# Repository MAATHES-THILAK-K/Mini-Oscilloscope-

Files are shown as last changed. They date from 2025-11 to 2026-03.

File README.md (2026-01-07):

# **Mini Oscilloscope – Arduino + SH1106 OLED**

A compact oscilloscope built using Arduino, an SH1106 OLED module, and a simple analog front-end.
Includes auto-range, trigger detection, waveform plotting, and frequency/duty-cycle measurement.

> **Reference Project Used:**
> This build was inspired by the project on Instructables:
> *“Build Your Own Arduino Nano Based DIY Oscilloscope”*
> *https://www.instructables.com/Build-Your-Own-Arduino-Nano-Based-DIY-Oscilloscope/*

---

## 🔧 **Features**

* SH1106 128×64 OLED display
* Auto/Manual voltage ranges
* Time-base options from **200 ms/div** to **200 µs/div**
* Trigger detection (rising & falling edge)
* Frequency and duty-cycle calculation
* Average voltage measurement
* EEPROM settings storage
* Battery measurement mode

---

## 📦 **Hardware**

### **Core Components**

* Arduino Nano (ATmega328P)
* SH1106 128×64 I²C OLED display
* Tactile push buttons (4×: SELECT, UP, DOWN, HOLD)
* Voltage divider resistors
* Schottky diode
* 104 capacitor
* Breadboard or custom PCB
* Jumper wires
* 5V regulated power supply

### **Additional Interface Components**

* Input attenuator (1× / 10×)
* User control buttons.

---

## 🧪 **How It Works**

* Samples analog input using ADC with a variable prescaler
* Computes minimum, maximum, and average voltage
* Detects trigger events to stabilize waveform display
* Calculates frequency and duty cycle using edge-cross detection
* Renders waveform using the **Adafruit GFX** library

---

## 🖼 **Photos / Screenshots**

Add images inside the `Images/` folder once your hardware build is ready.

---

## 📁 **Code Structure**

```
MiniOscilloscope/
├── src/
│   └── miniOscilloscope.ino
├── README.md
├── LICENSE
└── Images/
```

---

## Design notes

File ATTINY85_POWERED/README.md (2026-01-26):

# ATtiny85 Powered Mini Oscilloscope – PCB Design

This repository contains the complete PCB design files for a **compact, low-cost mini oscilloscope** powered by the **ATtiny85 microcontroller**.  
The project is intended for **educational, experimental, and embedded systems learning purposes**.

---

## 📷 PCB Preview

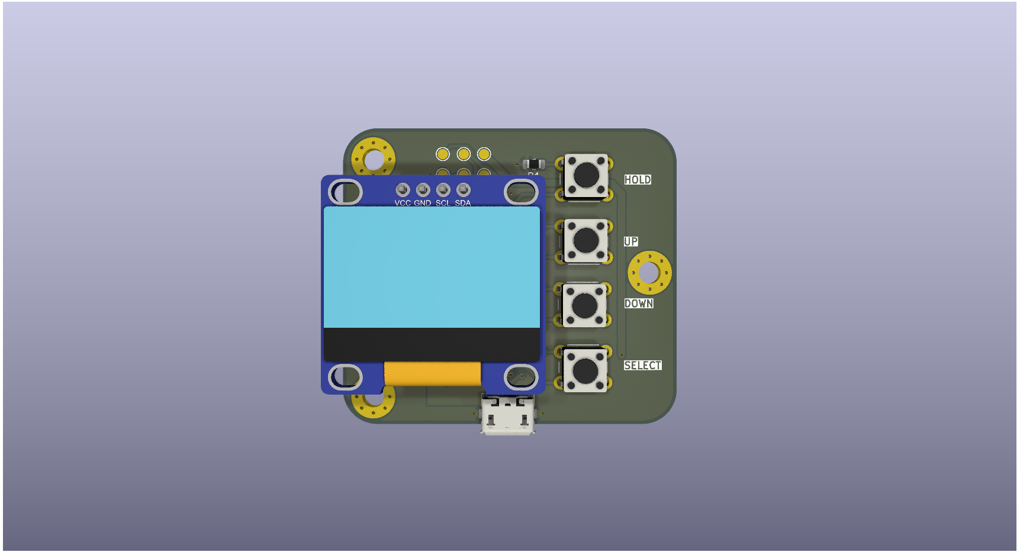
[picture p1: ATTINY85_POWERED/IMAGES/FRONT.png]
ATtiny85 Mini Oscilloscope PCB


---

## 📌 Features

- ATtiny85-based minimal oscilloscope design  
- Compact single-board PCB  
- Designed using **KiCad**
- Low component count for easy fabrication
- Suitable for low-frequency signal visualization
- Ideal for students and hobbyists

---

## 📂 Folder Structure

- **GERBER/** – Manufacturing-ready Gerber files  
- **IMAGES/** – PCB renders and images  
- **3D MODEL/** – 3D visualization of the PCB  
- **BACKUPS/** – Design backups  
- **REPORT/** – Project documentation  
- **POS.zip** – Pick and Place files  
- **\*.kicad_\*** – KiCad project, schematic, and PCB layout files  

---

## 🛠 Tools Used

- KiCad (Schematic & PCB Design)
- ATtiny85 Microcontroller

---

## ⚠️ Disclaimer

This oscilloscope is **not a replacement for professional instruments**.  
It is designed strictly for **learning, experimentation, and demonstration** purposes.

---

## 📜 License

This project is open-source and intended for educational use.  
Feel free to modify and improve the design with proper attribution.

---

### 🚀 Designed & Maintained by  
**MAATHES-THILAK-K**

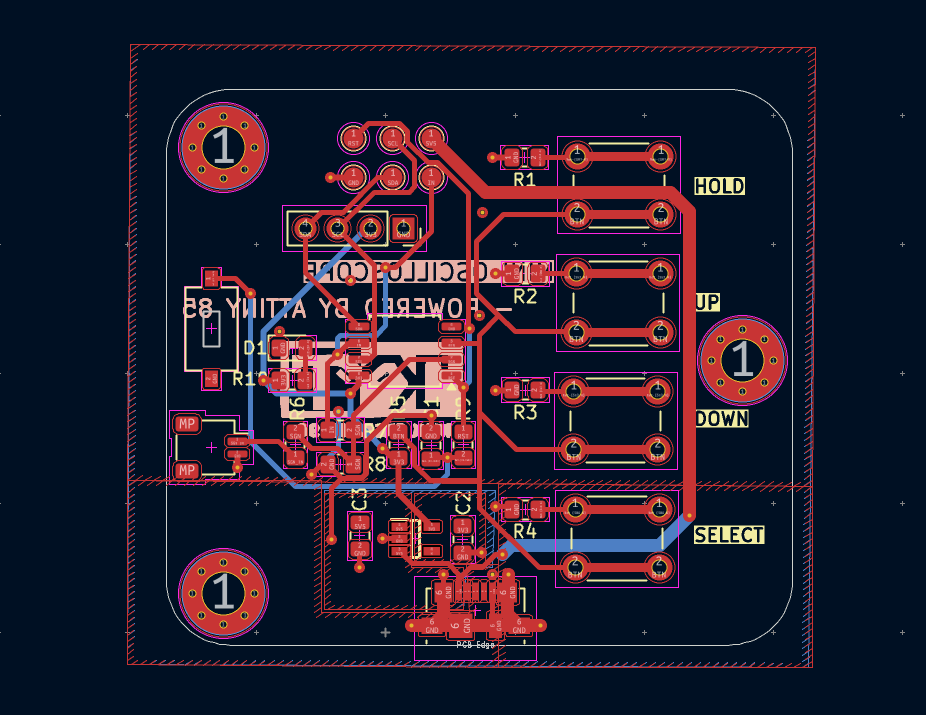
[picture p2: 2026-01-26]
ATTINY85_POWERED/IMAGES/LAYOUT_2.png

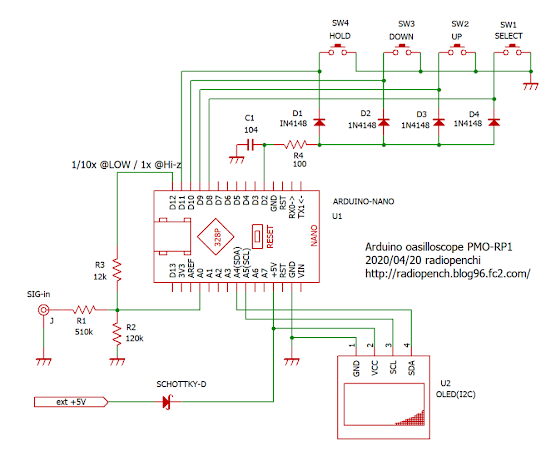
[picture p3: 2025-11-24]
Images/diagram.webp

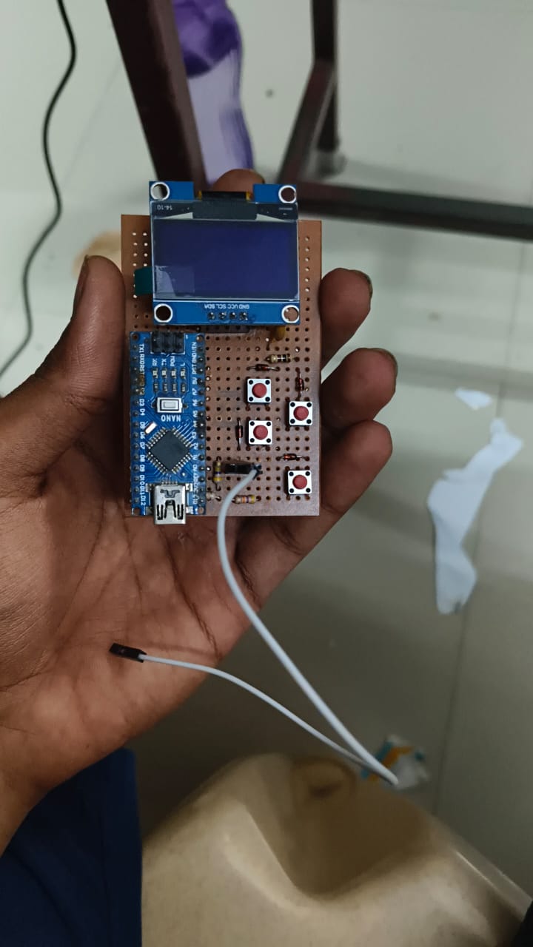
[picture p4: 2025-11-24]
Images/miniOscilloscope.jpeg

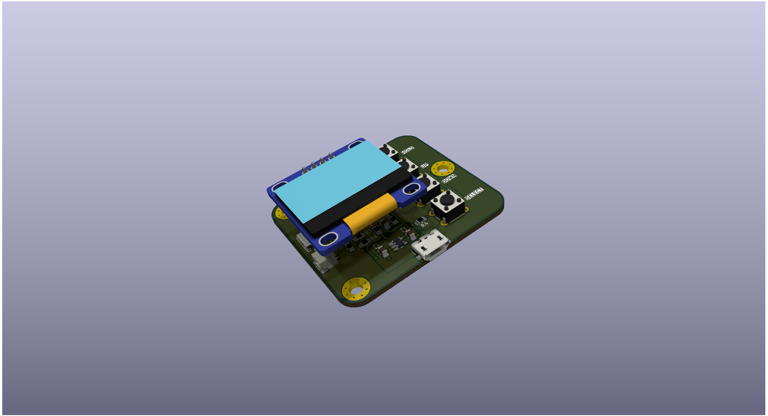
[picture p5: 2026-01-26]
ATTINY85_POWERED/IMAGES/ISOMETRIC.png

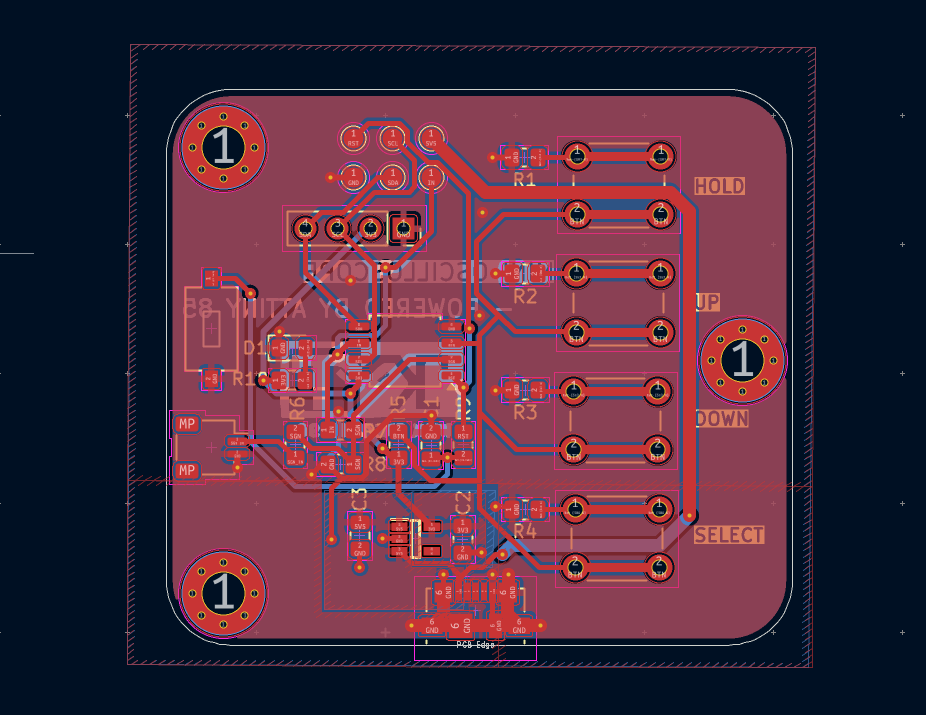
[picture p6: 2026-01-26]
ATTINY85_POWERED/IMAGES/LAYOUT_1.png

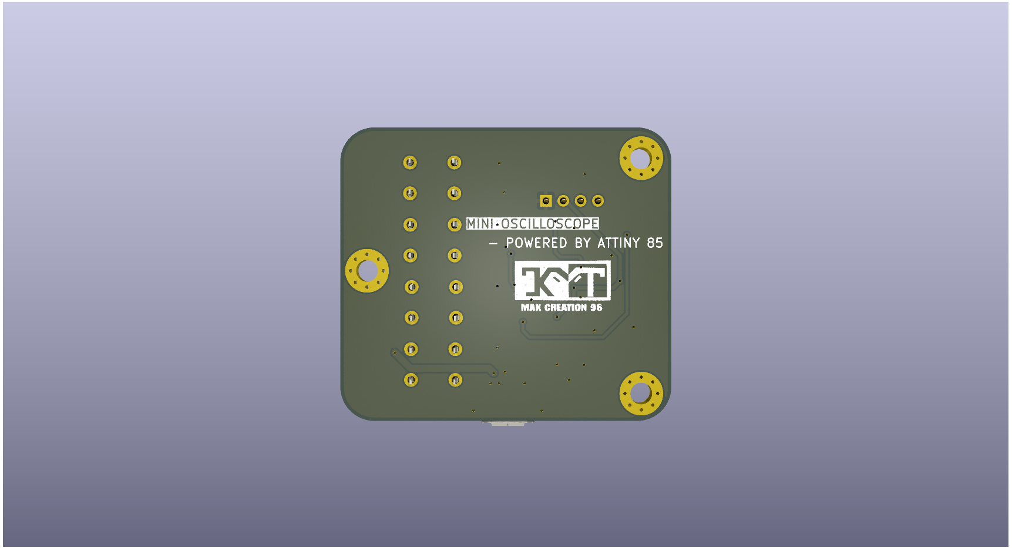
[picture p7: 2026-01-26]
ATTINY85_POWERED/IMAGES/BACK.png

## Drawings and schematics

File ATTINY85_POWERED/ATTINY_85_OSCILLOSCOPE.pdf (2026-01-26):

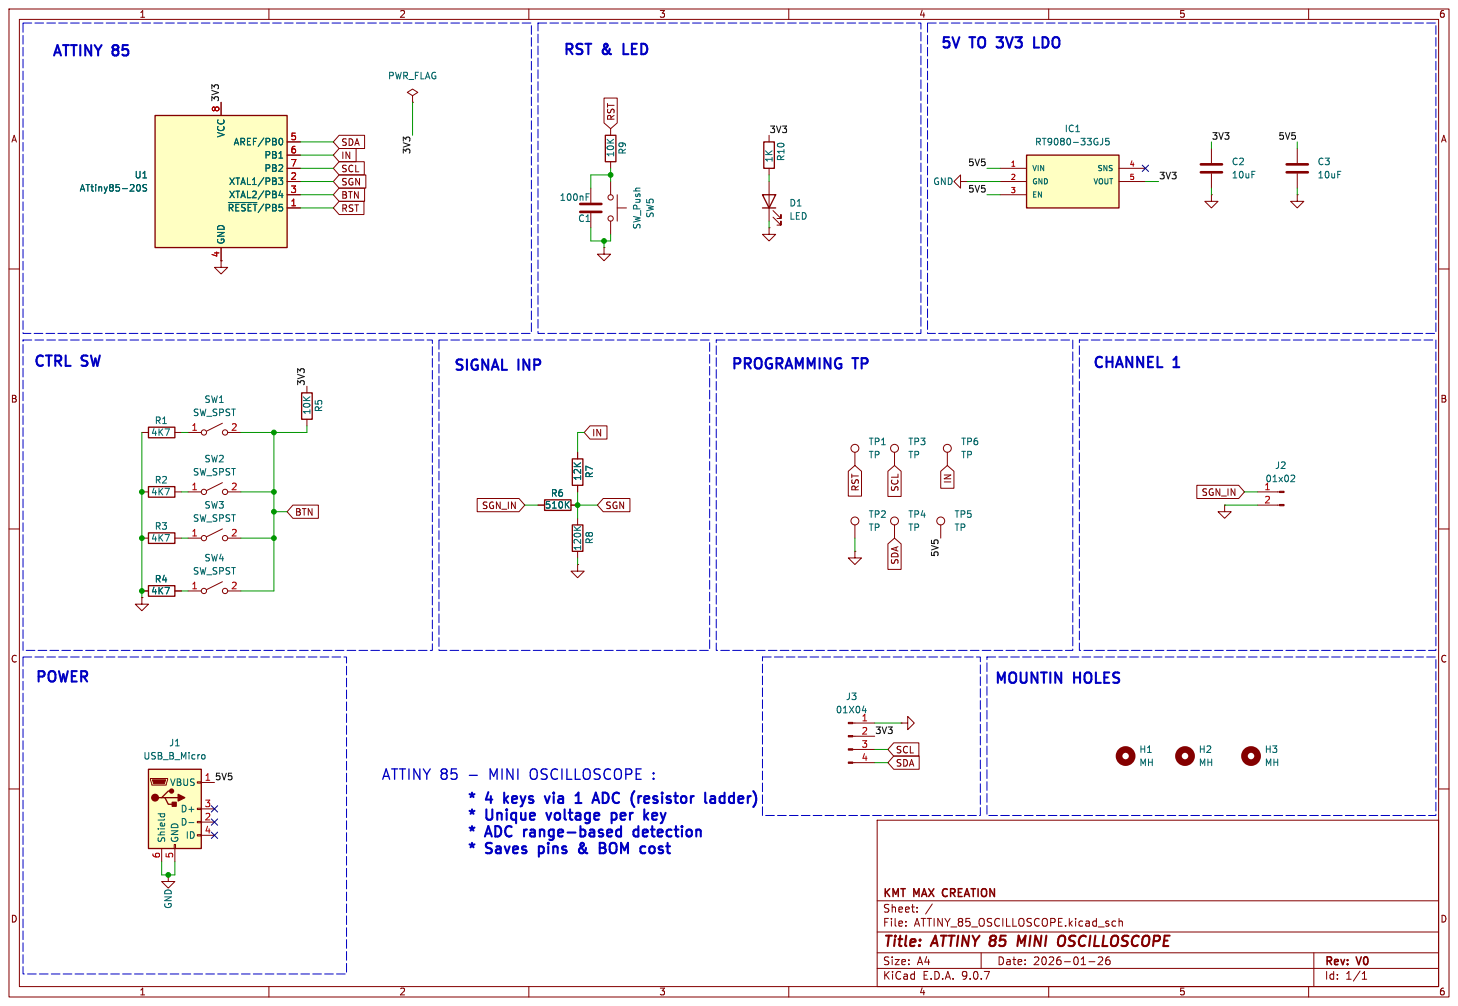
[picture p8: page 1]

* Saves pins & BOM cost

Id: 1/1 Title: ATTINY 85 MINI OSCILLOSCOPE

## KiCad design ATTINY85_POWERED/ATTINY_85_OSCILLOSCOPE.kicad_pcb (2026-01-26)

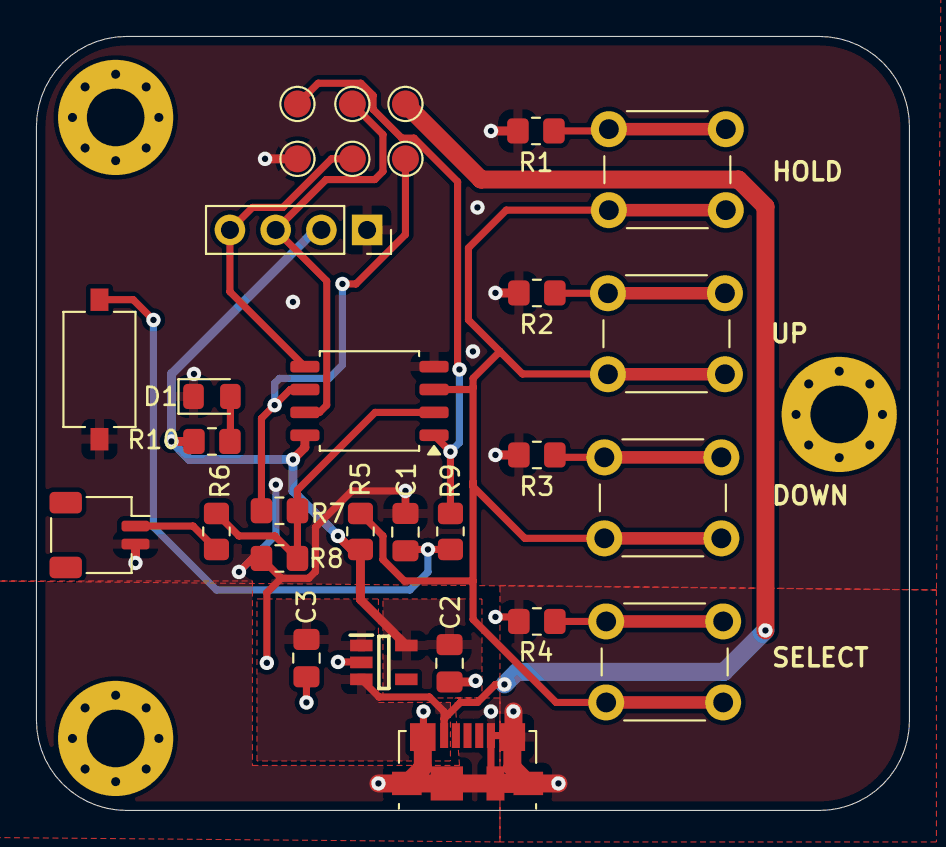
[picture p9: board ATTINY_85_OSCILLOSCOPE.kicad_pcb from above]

Board: 2 copper layers, 48.5 x 43.0 mm, 33 parts (0 on the bottom side), 16 nets.

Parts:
C1: 100nF; C_0805_2012Metric_Pad1.18x1.45mm_HandSolder
C2, C3: 10uF; C_0805_2012Metric_Pad1.18x1.45mm_HandSolder
D1: LED; LED_0805_2012Metric_Pad1.15x1.40mm_HandSolder
DOWN: SW_SPST; SW_PUSH_6mm
H1, H2, H3: MH; MountingHole_3.2mm_M3_Pad_Via
HOLD: SW_SPST; SW_PUSH_6mm
IC1: RT9080-33GJ5; SOT94P280X100-5N
J1: USB_B_Micro; USB_Micro-B_Molex_47346-0001
J2: 01x02; JST_SH_SM02B-SRSS-TB_1x02-1MP_P1.00mm_Horizontal
J3: 01X04; PinSocket_1x04_P2.54mm_Vertical
R1, R2, R3, R4: 4K7; R_0805_2012Metric_Pad1.20x1.40mm_HandSolder
R5, R9: 10K; R_0805_2012Metric_Pad1.20x1.40mm_HandSolder
R6: 510K; R_0805_2012Metric_Pad1.20x1.40mm_HandSolder
R7: 12K; R_0805_2012Metric_Pad1.20x1.40mm_HandSolder
R8: 120K; R_0805_2012Metric_Pad1.20x1.40mm_HandSolder
R10: 1K; R_0805_2012Metric_Pad1.20x1.40mm_HandSolder
SELECT: SW_SPST; SW_PUSH_6mm
SW5: SW_Push; SW_Tactile_SPST_NO_Straight_CK_PTS636Sx25SMTRLFS
TP1, TP2, TP3, TP4, TP5, TP6: TP; TestPoint_Pad_D1.5mm
U1: ATtiny85-20S; SOIC-8_5.3x5.3mm_P1.27mm
UP: SW_SPST; SW_PUSH_6mm

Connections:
/3V3: C2.1, IC1.5 (VOUT), J3.2, R5.1, R10.1, U1.8 (VCC)
/5V5: C3.1, IC1.1 (VIN), IC1.3 (EN), J1.1 (VBUS), TP5.1
BTN: DOWN.2 (B), HOLD.2 (B), R5.2, SELECT.2 (B), U1.3 (XTAL2/PB4), UP.2 (B)
GND: C1.2, C2.2, C3.2, D1.1 (K), IC1.2 (GND), J1.5 (GND), J1.6 (Shield), J2.2, J3.1, R1.1, R2.1, R3.1, R4.1, R8.2, SW5.2, TP2.1, U1.4 (GND)
IN: R7.1, TP6.1, U1.6 (PB1)
unnamed: C1.1, R9.2, SW5.1
unnamed: D1.2 (A), R10.2
unnamed: HOLD.1 (A), R1.2
unnamed: R2.2, UP.1 (A)
unnamed: DOWN.1 (A), R3.2
unnamed: R4.2, SELECT.1 (A)
RST: R9.1, TP1.1, U1.1 (~RESET/PB5)
SCL: J3.3, TP3.1, U1.7 (PB2)
SDA: J3.4, TP4.1, U1.5 (AREF/PB0)
SGN: R6.2, R7.2, R8.1, U1.2 (XTAL1/PB3)
SGN_IN: J2.1, R6.1

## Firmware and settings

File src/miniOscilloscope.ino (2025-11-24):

#include <Wire.h>
#include <Adafruit_GFX.h>
//#include <Adafruit_SSD1306.h>
#include <Adafruit_SH1106.h>            // https://github.com/wonho-maker/Adafruit_SH1106
#include <EEPROM.h>

#define SCREEN_WIDTH 128                // OLED display width
#define SCREEN_HEIGHT 64                // OLED display height
#define REC_LENG 200                    // size of wave data buffer
#define MIN_TRIG_SWING 5                // minimum trigger swing.(Display "Unsync" if swing smaller than this value

// Declaration for an SSD1306 display connected to I2C (SDA, SCL pins)
#define OLED_RESET     -1      // Reset pin # (or -1 if sharing Arduino reset pin)
//Adafruit_SSD1306 oled(SCREEN_WIDTH, SCREEN_HEIGHT, &Wire, OLED_RESET);   // device name is oled
Adafruit_SH1106 oled(OLED_RESET);        // use this when SH1106

// Range name table (those are stored in flash memory)
const char vRangeName[10][5] PROGMEM = {"A50V", "A 5V", " 50V", " 20V", " 10V", "  5V", "  2V", "  1V", "0.5V", "0.2V"}; // Vertical display character (number of characters including \ 0 is required)
const char * const vstring_table[] PROGMEM = {vRangeName[0], vRangeName[1], vRangeName[2], vRangeName[3], vRangeName[4], vRangeName[5], vRangeName[6], vRangeName[7], vRangeName[8], vRangeName[9]};
const char hRangeName[10][6] PROGMEM = {"200ms", "100ms", " 50ms", " 20ms", " 10ms", "  5ms", "  2ms", "  1ms", "500us", "200us"};  //  Hrizontal display characters
const char * const hstring_table[] PROGMEM = {hRangeName[0], hRangeName[1], hRangeName[2], hRangeName[3], hRangeName[4], hRangeName[5], hRangeName[6], hRangeName[7], hRangeName[8], hRangeName[9]};
const PROGMEM float hRangeValue[] = { 0.2, 0.1, 0.05, 0.02, 0.01, 0.005, 0.002, 0.001, 0.5e-3, 0.2e-3}; // horizontal range value in second. ( = 25pix on screen)

int waveBuff[REC_LENG];        // wave form buffer (RAM remaining capacity is barely)
char chrBuff[8];               // display string buffer
char hScale[] = "xxxAs";       // horizontal scale character
char vScale[] = "xxxx";        // vartical scale

float lsb5V = 0.00566826;      // sensivity coefficient of 5V range. std=0.00563965 1.1*630/(1024*120)
float lsb50V = 0.05243212;     // sensivity coefficient of 50V range. std=0.0512898 1.1*520.91/(1024*10.91)

volatile int vRange;           // V-range number 0:A50V,  1:A 5V,  2:50V,  3:20V,  4:10V,  5:5V,  6:2V,  7:1V,  8:0.5V,  9:0.2V
volatile int hRange;           // H-range nubmer 0:200ms, 1:100ms, 2:50ms, 3:20ms, 4:10ms, 5:5ms, 6;2ms, 7:1ms, 8:500us, 9;200us
volatile int trigD;            // trigger slope flag,     0:positive 1:negative
volatile int scopeP;           // operation scope position number. 0:Veratical, 1:Hrizontal, 2:Trigger slope
volatile boolean hold = false; // hold flag
volatile boolean switchPushed = false; // flag of switch pusshed !
volatile int saveTimer;        // remaining time for saving EEPROM
int timeExec;                  // approx. execution time of current range setting (ms)

int dataMin;                   // buffer minimum value (smallest=0)
int dataMax;                   //        maximum value (largest=1023)
int dataAve;                   // 10 x average value (use 10x value to keep accuracy. so, max=10230)
int rangeMax;                  // buffer value to graph full swing
int rangeMin;                  // buffer value of graph botto
int rangeMaxDisp;              // display value of max. (100x value)
int rangeMinDisp;              // display value if min.
int trigP;                     // trigger position pointer on data buffer
boolean trigSync;              // flag of trigger detected
int att10x;                    // 10x attenetor ON (effective when 1)

float waveFreq;                // frequency (Hz)
float waveDuty;                // duty ratio (%)

void setup() {
  pinMode(2, INPUT_PULLUP);             // button pussed interrupt (int.0 IRQ)
  pinMode(8, INPUT_PULLUP);             // Select button
  pinMode(9, INPUT_PULLUP);             // Up
  pinMode(10, INPUT_PULLUP);            // Down
  pinMode(11, INPUT_PULLUP);            // Hold
  pinMode(12, INPUT);                   // 1/10 attenuator(Off=High-Z, Enable=Output Low)
  pinMode(13, OUTPUT);                  // LED

// oled.begin(SSD1306_SWITCHCAPVCC, 0x3C) { // select 3C or 3D (set your OLED I2C address)
  oled.begin(SH1106_SWITCHCAPVCC, 0x3C);  // use this when SH1106 
  oled.setRotation(2);
  auxFunctions();                       // Voltage measure (never return)
  loadEEPROM();                         // read last settings from EEPROM
  analogReference(INTERNAL);            // ADC full scale = 1.1V
  attachInterrupt(0, pin2IRQ, FALLING); // activate IRQ at falling edge mode
  startScreen();                        // display start message
}

void loop() {
  setConditions();                      // set measurment conditions
  digitalWrite(13, HIGH);               // flash LED
  readWave();                           // read wave form and store into buffer memory
  digitalWrite(13, LOW);                // stop LED
  setConditions();                      // set measurment conditions again (reflect change during measure)
  dataAnalize();                        // analize data
  writeCommonImage();                   // write fixed screen image (2.6ms)
  plotData();                           // plot waveform (10-18ms)
  dispInf();                            // display information (6.5-8.5ms)
  oled.display();                       // send screen buffer to OLED (37ms)
  saveEEPROM();                         // save settings to EEPROM if necessary
  while (hold == true) {                // wait if Hold flag ON
    dispHold();
    delay(10);
  }                                     // loop cycle speed = 60-470ms (buffer size = 200)
}

void setConditions() {           // measuring condition setting
  // get range name from PROGMEM
  strcpy_P(hScale, (char*)pgm_read_word(&(hstring_table[hRange])));  // H range name
  strcpy_P(vScale, (char*)pgm_read_word(&(vstring_table[vRange])));  // V range name

  switch (vRange) {              // setting of Vrange
    case 0: {                    // Auto50V range
        att10x = 1;              // use input attenuator
        break;
      }
    case 1: {                    // Auto 5V range
        att10x = 0;              // no attenuator
        break;
      }
    case 2: {                    // 50V range
        rangeMax = 50 / lsb50V;  // set full scale pixcel count number
        rangeMaxDisp = 5000;     // vartical scale (set100x value)
        rangeMin = 0;
        rangeMinDisp = 0;
        att10x = 1;              // use input attenuator
        break;
      }
    case 3: {                    // 20V range
        rangeMax = 20 / lsb50V;  // set full scale pixcel count number
        rangeMaxDisp = 2000;
        rangeMin = 0;
        rangeMinDisp = 0;
        att10x = 1;              // use input attenuator
        break;
      }
    case 4: {                    // 10V range
        rangeMax = 10 / lsb50V;  // set full scale pixcel count number
        rangeMaxDisp = 1000;
        rangeMin = 0;
        rangeMinDisp = 0;
        att10x = 1;              // use input attenuator
        break;
      }
    case 5: {                    // 5V range
        rangeMax = 5 / lsb5V;    // set full scale pixcel count number
        rangeMaxDisp = 500;
        rangeMin = 0;
        rangeMinDisp = 0;
        att10x = 0;              // no input attenuator
        break;
      }
    case 6: {                    // 2V range
        rangeMax = 2 / lsb5V;    // set full scale pixcel count number
        rangeMaxDisp = 200;
        rangeMin = 0;
        rangeMinDisp = 0;
        att10x = 0;              // no input attenuator
        break;
      }
    case 7: {                    // 1V range
        rangeMax = 1 / lsb5V;    // set full scale pixcel count number
        rangeMaxDisp = 100;
        rangeMin = 0;
        rangeMinDisp = 0;
        att10x = 0;              // no input attenuator
        break;
      }
    case 8: {                    // 0.5V range
        rangeMax = 0.5 / lsb5V;  // set full scale pixcel count number
        rangeMaxDisp = 50;
        rangeMin = 0;
        rangeMinDisp = 0;
        att10x = 0;              // no input attenuator
        break;
      }
    case 9: {                    // 0.5V range
        rangeMax = 0.2 / lsb5V;  // set full scale pixcel count number
        rangeMaxDisp = 20;
        rangeMin = 0;
        rangeMinDisp = 0;
        att10x = 0;              // no input attenuator
        break;
      }
  }
}

void writeCommonImage() {                 // Common screen image drawing
  oled.clearDisplay();                    // erase all(0.4ms)
  oled.setTextColor(WHITE);               // write in white character
  oled.setCursor(85, 0);                  // Start at top-left corner
  oled.println(F("av    v"));             // 1-st line fixed characters
  oled.drawFastVLine(26, 9, 55, WHITE);   // left vartical line
  oled.drawFastVLine(127, 9, 3, WHITE);   // right vrtical line up
  oled.drawFastVLine(127, 61, 3, WHITE);  // right vrtical line bottom

  oled.drawFastHLine(24, 9, 7, WHITE);    // Max value auxiliary mark
  oled.drawFastHLine(24, 36, 2, WHITE);
  oled.drawFastHLine(24, 63, 7, WHITE);

  oled.drawFastHLine(51, 9, 3, WHITE);    // Max value auxiliary mark
  oled.drawFastHLine(51, 63, 3, WHITE);

  oled.drawFastHLine(76, 9, 3, WHITE);    // Max value auxiliary mark
  oled.drawFastHLine(76, 63, 3, WHITE);

  oled.drawFastHLine(101, 9, 3, WHITE);   // Max value auxiliary mark
  oled.drawFastHLine(101, 63, 3, WHITE);

  oled.drawFastHLine(123, 9, 5, WHITE);   // right side Max value auxiliary mark
  oled.drawFastHLine(123, 63, 5, WHITE);

  for (int x = 26; x <= 128; x += 5) {
    oled.drawFastHLine(x, 36, 2, WHITE);  // Draw the center line (horizontal line) with a dotted line
  }
  for (int x = (127 - 25); x > 30; x -= 25) {
    for (int y = 10; y < 63; y += 5) {
      oled.drawFastVLine(x, y, 2, WHITE); // Draw 3 vertical lines with dotted lines
    }
  }
}

void readWave() {                            // Record waveform to memory array
  if (att10x == 1) {                         // if 1/10 attenuator required
    pinMode(12, OUTPUT);                     // assign attenuator controle pin to OUTPUT,
    digitalWrite(12, LOW);                   // and output LOW (output 0V)
  } else {                                   // if not required
    pinMode(12, INPUT);                      // assign the pin input (Hi-z)
  }
  switchPushed = false;                      // Clear switch operation flag

  switch (hRange) {                          // set recording conditions in accordance with the range number
    case 0: {                                // 200ms range
        timeExec = 1600 + 60;                // Approximate execution time(ms) Used for countdown until saving to EEPROM
        ADCSRA = ADCSRA & 0xf8;              // clear bottom 3bit
        ADCSRA = ADCSRA | 0x07;              // dividing ratio = 128 (default of Arduino）
        for (int i = 0; i < REC_LENG; i++) { // up to rec buffer size
          waveBuff[i] = analogRead(0);       // read and save approx 112us
          delayMicroseconds(7888);           // timing adjustment
          if (switchPushed == true) {        // if any switch touched
            switchPushed = false;
            break;                           // abandon record(this improve response)
          }
        }
        break;
      }
    case 1: {                                // 100ms range
        timeExec = 800 + 60;                 // Approximate execution time(ms) Used for countdown until saving to EEPROM
        ADCSRA = ADCSRA & 0xf8;              // clear bottom 3bit
        ADCSRA = ADCSRA | 0x07;              // dividing ratio = 128 (default of Arduino）
        for (int i = 0; i < REC_LENG; i++) {  // up to rec buffer size
          waveBuff[i] = analogRead(0);       // read and save approx 112us
          // delayMicroseconds(3888);           // timing adjustmet
          delayMicroseconds(3860);           // timing adjustmet tuned
          if (switchPushed == true) {        // if any switch touched
            switchPushed = false;
            break;                           // abandon record(this improve response)
          }
        }
        break;
      }
    case 2: {                                // 50ms range
        timeExec = 400 + 60;                 // Approximate execution time(ms)
        ADCSRA = ADCSRA & 0xf8;              // clear bottom 3bit
        ADCSRA = ADCSRA | 0x07;              // dividing ratio = 128 (default of Arduino）
        for (int i = 0; i < REC_LENG; i++) { // up to rec buffer size
          waveBuff[i] = analogRead(0);       // read and save approx 112us
          // delayMicroseconds(1888);           // timing adjustmet
          delayMicroseconds(1880);           // timing adjustmet tuned

          if (switchPushed == true) {        // if any switch touched
            break;                           // abandon record(this improve response)
          }
        }
        break;
      }
    case 3: {                                // 20ms range
        timeExec = 160 + 60;                 // Approximate execution time(ms)
        ADCSRA = ADCSRA & 0xf8;              // clear bottom 3bit
        ADCSRA = ADCSRA | 0x07;              // dividing ratio = 128 (default of Arduino）
        for (int i = 0; i < REC_LENG; i++) { // up to rec buffer size
          waveBuff[i] = analogRead(0);       // read and save approx 112us
          // delayMicroseconds(688);            // timing adjustmet
          delayMicroseconds(686);            // timing adjustmet tuned
          if (switchPushed == true) {        // if any switch touched
            break;                           // abandon record(this improve response)
          }
        }
        break;
      }
    case 4: {                                // 10ms range
        timeExec = 80 + 60;                  // Approximate execution time(ms)
        ADCSRA = ADCSRA & 0xf8;              // clear bottom 3bit
        ADCSRA = ADCSRA | 0x07;              // dividing ratio = 128 (default of Arduino）
        for (int i = 0; i < REC_LENG; i++) { // up to rec buffer size
          waveBuff[i] = analogRead(0);       // read and save approx 112us
          // delayMicroseconds(288);            // timing adjustmet
          delayMicroseconds(287);            // timing adjustmet tuned
          if (switchPushed == true) {        // if any switch touched
            break;                           // abandon record(this improve response)
          }
        }
        break;
      }
    case 5: {                                // 5ms range
        timeExec = 40 + 60;                  // Approximate execution time(ms)
        ADCSRA = ADCSRA & 0xf8;              // clear bottom 3bit
        ADCSRA = ADCSRA | 0x07;              // dividing ratio = 128 (default of Arduino）
        for (int i = 0; i < REC_LENG; i++) { // up to rec buffer size
          waveBuff[i] = analogRead(0);       // read and save approx 112μs
          // delayMicroseconds(88);             // timing adjustmet
          delayMicroseconds(87);             // timing adjustmet tuned
          if (switchPushed == true) {        // if any switch touched
            break;                           // abandon record(this improve response)
          }
        }
        break;
      }
    case 6: {                                // 2ms range
        timeExec = 16 + 60;                  // Approximate execution time(ms)
        ADCSRA = ADCSRA & 0xf8;              // clear bottom 3bit
        ADCSRA = ADCSRA | 0x06;              // dividing ratio = 64 (0x1=2, 0x2=4, 0x3=8, 0x4=16, 0x5=32, 0x6=64, 0x7=128)
        for (int i = 0; i < REC_LENG; i++) { // up to rec buffer size
          waveBuff[i] = analogRead(0);       // read and save approx 56us
          // delayMicroseconds(24);             // timing adjustmet
          delayMicroseconds(23);             // timing adjustmet tuned
        }
        break;
      }
    case 7: {                                // 1ms range
        timeExec = 8 + 60;                   // Approximate execution time(ms)
        ADCSRA = ADCSRA & 0xf8;              // clear bottom 3bit
        ADCSRA = ADCSRA | 0x05;              // dividing ratio = 16 (0x1=2, 0x2=4, 0x3=8, 0x4=16, 0x5=32, 0x6=64, 0x7=128)
        for (int i = 0; i < REC_LENG; i++) { // up to rec buffer size
          waveBuff[i] = analogRead(0);       // read and save approx 28us
          // delayMicroseconds(12);             // timing adjustmet
          delayMicroseconds(10);             // timing adjustmet tuned
        }
        break;
      }
    case 8: {                                // 500us range
        timeExec = 4 + 60;                   // Approximate execution time(ms)
        ADCSRA = ADCSRA & 0xf8;              // clear bottom 3bit
        ADCSRA = ADCSRA | 0x04;              // dividing ratio = 16(0x1=2, 0x2=4, 0x3=8, 0x4=16, 0x5=32, 0x6=64, 0x7=128)
        for (int i = 0; i < REC_LENG; i++) { // up to rec buffer size
          waveBuff[i] = analogRead(0);       // read and save approx 16us
          delayMicroseconds(4);              // timing adjustmet
          // time fine adjustment 0.0625 x 8 = 0.5us（nop=0.0625us @16MHz)
          asm("nop"); asm("nop"); asm("nop"); asm("nop"); asm("nop"); asm("nop"); asm("nop"); asm("nop");
        }
        break;
      }
    case 9: {                                // 200us range
        timeExec = 2 + 60;                   // Approximate execution time(ms)
        ADCSRA = ADCSRA & 0xf8;              // clear bottom 3bit
        ADCSRA = ADCSRA | 0x02;              // dividing ratio = 4(0x1=2, 0x2=4, 0x3=8, 0x4=16, 0x5=32, 0x6=64, 0x7=128)
        for (int i = 0; i < REC_LENG; i++) { // up to rec buffer size
          waveBuff[i] = analogRead(0);       // read and save approx 6us
          // time fine adjustment 0.0625 * 20 = 1.25us (nop=0.0625us @16MHz)
          asm("nop"); asm("nop"); asm("nop"); asm("nop"); asm("nop"); asm("nop"); asm("nop"); asm("nop"); asm("nop"); asm("nop");
          asm("nop"); asm("nop"); asm("nop"); asm("nop"); asm("nop"); asm("nop"); asm("nop"); asm("nop"); asm("nop"); asm("nop");
        }
        break;
      }
  }
}

void dataAnalize() {                       // get various information from wave form
  int d;
  long sum = 0;

  // search max and min value
  dataMin = 1023;                          // min value initialize to big number
  dataMax = 0;                             // max value initialize to small number
  for (int i = 0; i < REC_LENG; i++) {     // serach max min value
    d = waveBuff[i];
    sum = sum + d;
    if (d < dataMin) {                     // update min
      dataMin = d;
    }
    if (d > dataMax) {                     // updata max
      dataMax = d;
    }
  }

  // calculate average
  dataAve = (sum + 10) / 20;               // Average value calculation (calculated by 10 times to improve accuracy)

  // decide display's max min value
  if (vRange <= 1) {                       // if Autorabge(Range number <=1）
    rangeMin = dataMin - 20;               // maintain bottom margin 20
    rangeMin = (rangeMin / 10) * 10;       // round 10
    if (rangeMin < 0) {
      rangeMin = 0;                        // no smaller than 0
    }
    rangeMax = dataMax + 20;               // set display top at  data max +20
    rangeMax = ((rangeMax / 10) + 1) * 10; // round up 10
    if (rangeMax > 1020) {
      rangeMax = 1023;                     // if more than 1020, hold down at 1023
    }

    if (att10x == 1) {                            // if 10x attenuator used
      rangeMaxDisp = 100 * (rangeMax * lsb50V);   // display range is determined by the data.(the upper limit is up to the full scale of the ADC)
      rangeMinDisp = 100 * (rangeMin * lsb50V);   // lower depend on data, but zero or more
    } else {                                      // if no attenuator used
      rangeMaxDisp = 100 * (rangeMax * lsb5V);
      rangeMinDisp = 100 * (rangeMin * lsb5V);
    }
  } else {                                        // if fix range
    // Write necessary code here (none for now)
  }

  // Trigger position search
  for (trigP = ((REC_LENG / 2) - 51); trigP < ((REC_LENG / 2) + 50); trigP++) { // Find the points that straddle the median at the center ± 50 of the data range
    if (trigD == 0) {                             // if trigger direction is positive
      if ((waveBuff[trigP - 1] < (dataMax + dataMin) / 2) && (waveBuff[trigP] >= (dataMax + dataMin) / 2)) {
        break;                                    // positive trigger position found !
      }
    } else {                                      // trigger direction is negative
      if ((waveBuff[trigP - 1] > (dataMax + dataMin) / 2) && (waveBuff[trigP] <= (dataMax + dataMin) / 2)) {
        break;
      }                                           // negative trigger poshition found !
    }
  }
  trigSync = true;
  if (trigP >= ((REC_LENG / 2) + 50)) {           // If the trigger is not found in range
    trigP = (REC_LENG / 2);                       // Set it to the center for the time being
    trigSync = false;                             // set Unsync display flag
  }
  if ((dataMax - dataMin) <= MIN_TRIG_SWING) {    // amplitude of the waveform smaller than the specified value
    trigSync = false;                             // set Unsync display flag
  }
  freqDuty();
}
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

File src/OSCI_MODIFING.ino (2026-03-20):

#include <Wire.h>
#include <U8g2lib.h>
#include <EEPROM.h>

U8G2_SH1106_128X64_NONAME_1_HW_I2C oled(U8G2_R0, U8X8_PIN_NONE);

#define REC_LEN 200
#define MIN_TRIG_SWING 5
#define LSB_5V 0.00566826f
#define LSB_50V 0.05243212f

// ── PROGMEM tables ────────────────────────────────────────────────────────────
const char vName[10][5] PROGMEM = {
  "A50V", "A 5V", " 50V", " 20V", " 10V", "  5V", "  2V", "  1V", "0.5V", "0.2V"
};
const char hName[10][6] PROGMEM = {
  "200ms", "100ms", " 50ms", " 20ms", " 10ms", "  5ms", "  2ms", "  1ms", "500us", "200us"
};
const float H_SEC[10] PROGMEM = {
  0.2f, 0.1f, 0.05f, 0.02f, 0.01f, 0.005f, 0.002f, 0.001f, 5e-4f, 2e-4f
};

// V-range: fullScaleV (0=auto), dispMax (×100), att10x
struct VCfg {
  float fsV;
  int16_t dMax;
  uint8_t att;
};
const VCfg V_CFG[10] PROGMEM = {
  { 0, 0, 1 }, { 0, 0, 0 }, { 50, 5000, 1 }, { 20, 2000, 1 }, { 10, 1000, 1 }, { 5, 500, 0 }, { 2, 200, 0 }, { 1, 100, 0 }, { 0.5f, 50, 0 }, { 0.2f, 20, 0 }
};

// H-range: ADC prescaler bits, delay_µs, execMs
struct HCfg {
  uint8_t adcBits;
  uint16_t delayUs;
  uint16_t execMs;
};
const HCfg H_CFG[10] PROGMEM = {
  { 0x07, 7888, 1660 }, { 0x07, 3860, 860 }, { 0x07, 1880, 460 }, { 0x07, 686, 220 }, { 0x07, 287, 140 }, { 0x07, 87, 100 }, { 0x06, 23, 76 }, { 0x05, 10, 68 }, { 0x04, 0, 64 }, { 0x02, 0, 62 }
};

// ── RAM ──────────────────────────────────────────────────────────────────────
// CHANGE: int16_t → uint8_t saves 200 bytes (ADC stored as >>2, range 0-255)
uint8_t waveBuff[REC_LEN];
char chrBuff[8];

// CHANGE: tighter types for dataMin/Max (now 0-255), trigP (0-199)
volatile int8_t vRange = 3, hRange = 3, trigD = 1, scopeP = 1;
volatile bool switchPushed = false;
volatile int16_t saveTimer = 0;

uint16_t timeExec;
uint8_t dataMin, dataMax;  // 0-255 now
int16_t dataAve;
int16_t rangeMax, rangeMin;
int16_t rangeMaxDisp, rangeMinDisp;
uint8_t trigP;  // 0-199
bool trigSync;
uint8_t att10x;
// REMOVED: waveFreq, waveDuty, hold

// ── Helpers ───────────────────────────────────────────────────────────────────
inline int16_t sum3(int i) {
  return waveBuff[i - 1] + waveBuff[i] + waveBuff[i + 1];
}
inline void setADC(uint8_t bits) {
  ADCSRA = (ADCSRA & 0xF8) | bits;
}

// ── Setup / Loop ──────────────────────────────────────────────────────────────
void setup() {
  pinMode(2,INPUT_PULLUP); pinMode(8,INPUT_PULLUP); pinMode(9,INPUT_PULLUP);
  pinMode(10,INPUT_PULLUP); pinMode(11,INPUT_PULLUP);
  pinMode(12,INPUT); pinMode(13,OUTPUT);

  oled.begin();                        // ← was oled.begin(SH1106_SWITCHCAPVCC, 0x3C)
  oled.setFont(u8g2_font_5x7_tf);     // ← set once here, reuse everywhere

  loadEEPROM();
  analogReference(INTERNAL);
  attachInterrupt(0, pin2IRQ, FALLING);
  startScreen();
}

void loop() {
  setConditions();
  digitalWrite(13, HIGH);
  readWave();
  digitalWrite(13, LOW);
  setConditions();
  dataAnalize();

  // ── Page-mode draw loop (replaces clearDisplay + display) ──
  oled.firstPage();
  do {
    writeCommonImage();
    plotData();
    dispInf();
  } while (oled.nextPage());

  saveEEPROM();
}

// ── Conditions ────────────────────────────────────────────────────────────────
void setConditions() {
  VCfg vc; memcpy_P(&vc, &V_CFG[vRange], sizeof(vc));
  att10x = vc.att;
  if (vRange >= 2) {
    float lsb = att10x ? LSB_50V : LSB_5V;
    // CHANGE: >>2 because waveBuff is now 8-bit (ADC>>2)
    rangeMax     = (int16_t)(vc.fsV / lsb) >> 2;
    rangeMaxDisp = vc.dMax;
    rangeMin = rangeMinDisp = 0;
  }
}

// ── Wave Recording ────────────────────────────────────────────────────────────
void readWave() {
  if (att10x) {
    pinMode(12, OUTPUT);
    digitalWrite(12, LOW);
  } else {
    pinMode(12, INPUT);
  }
  switchPushed = false;

  HCfg hc;
  memcpy_P(&hc, &H_CFG[hRange], sizeof(hc));
  setADC(hc.adcBits);
  timeExec = hc.execMs;

  if (hRange <= 7) {
    for (int i = 0; i < REC_LEN; i++) {
      waveBuff[i] = (uint8_t)(analogRead(0) >> 2);
      if (hc.delayUs) delayMicroseconds(hc.delayUs);
      if (switchPushed) {
        switchPushed = false;
        break;
      }
    }
  } else if (hRange == 8) {
    for (int i = 0; i < REC_LEN; i++) {
      waveBuff[i] = (uint8_t)(analogRead(0) >> 2);
      delayMicroseconds(4);
      asm volatile("nop\nnop\nnop\nnop\nnop\nnop\nnop\nnop");
    }
  } else {
    for (int i = 0; i < REC_LEN; i++) {
      waveBuff[i] = (uint8_t)(analogRead(0) >> 2);
      asm volatile(
        "nop\nnop\nnop\nnop\nnop\nnop\nnop\nnop\nnop\nnop\n"
        "nop\nnop\nnop\nnop\nnop\nnop\nnop\nnop\nnop\nnop");
    }
  }
}

// ── Data Analysis ─────────────────────────────────────────────────────────────
void dataAnalize() {
  long sum = 0;
  dataMin = 255; dataMax = 0;           // 8-bit range now

  for (int i = 0; i < REC_LEN; i++) {
    uint8_t d = waveBuff[i];
    sum += d;
    if (d < dataMin) dataMin = d;
    if (d > dataMax) dataMax = d;
  }
  dataAve = (int16_t)((sum + 10) / 20); // still 10× avg, fits int16_t

  if (vRange <= 1) {
    // CHANGE: scaled for 8-bit (divide thresholds by 4)
    rangeMin = (uint8_t)max(0,   ((dataMin - 5) / 2) * 2);
    rangeMax = (uint8_t)min(255, (((dataMax + 5) / 2) + 1) * 2);
    float lsb4 = (att10x ? LSB_50V : LSB_5V) * 4.0f; // ×4 for >>2 shift
    rangeMaxDisp = (int16_t)(100.0f * rangeMax * lsb4);
    rangeMinDisp = (int16_t)(100.0f * rangeMin * lsb4);
  }

  uint8_t mid = (dataMax + dataMin) / 2;
  trigSync = false;
  for (trigP = (REC_LEN/2-51); trigP < (REC_LEN/2+50); trigP++) {
    bool posi = !trigD && waveBuff[trigP-1] <  mid && waveBuff[trigP] >= mid;
    bool nega =  trigD && waveBuff[trigP-1] >  mid && waveBuff[trigP] <= mid;
    if (posi || nega) { trigSync = true; break; }
  }
  if (!trigSync) trigP = REC_LEN / 2;
  if ((dataMax - dataMin) <= MIN_TRIG_SWING) trigSync = false;
  // REMOVED: freqDuty() call
}

// ── Display ───────────────────────────────────────────────────────────────────
void writeCommonImage() {
  // clearDisplay() NOT needed — page loop auto-clears each pass

  oled.setCursor(85, 6);               // y: 0→6
  oled.print(F("av    v"));            // println→print

  oled.drawVLine(26,  9, 55);
  oled.drawVLine(127, 9,  3);
  oled.drawVLine(127,61,  3);
  oled.drawHLine(24, 36,  2);

  const uint8_t hx[] PROGMEM = {24,51,76,101,123};
  for (uint8_t i = 0; i < 5; i++) {
    uint8_t x = pgm_read_byte(&hx[i]);
    uint8_t w = (i==0 || i==4) ? 7 : 3;
    oled.drawHLine(x,  9, w);
    oled.drawHLine(x, 63, w);
  }
  for (int x = 26;  x <= 128; x += 5)  oled.drawHLine(x, 36, 2);
  for (int x = 102; x > 30;   x -= 25)
    for (int y = 10; y < 63; y += 5)   oled.drawVLine(x, y, 2);
}

void plotData() {
  for (int x = 0; x <= 98; x++) {
    int y1 = constrain(map(waveBuff[x   + trigP - 50], rangeMin, rangeMax, 63, 9), 9, 63);
    int y2 = constrain(map(waveBuff[x+1 + trigP - 50], rangeMin, rangeMax, 63, 9), 9, 63);
    oled.drawLine(x+27, y1, x+28, y2);    // ← removed WHITE param
  }
}
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
